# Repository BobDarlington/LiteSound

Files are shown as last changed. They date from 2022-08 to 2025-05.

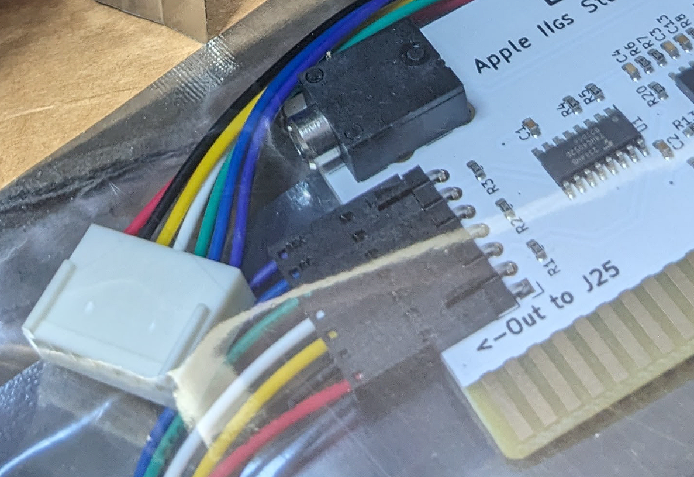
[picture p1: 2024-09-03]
cable-closeup.png

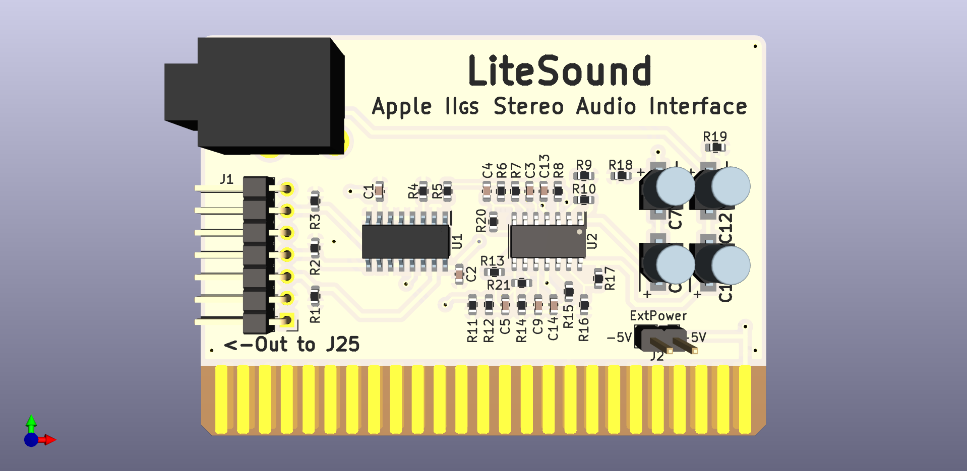
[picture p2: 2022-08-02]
IIGS-audio.png

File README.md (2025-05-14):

# LiteSound
This card provides stereo audio capability for the Apple IIGS computers.

This project was done in <b>KiCad 6.0.10</b> and may not work with older versions.

Installation and use manual is a Google Docs file and can be found at this URL:
https://tinyurl.com/39kpvvwv



The J25 header on the IIGS motherboard provides an analog audio signal, and address lines
to drive a demultiplexer which splits audio into Left & Right audio channels.

You can find partially made cables on eBay by searching for 7 pin 2510 or KF2510 cables, 30cm long.  
This length is "about right" and will reach all slots.  Pin 1 on the J25 goes to pin 7 on the LiteSound board.  
This is basically flipped or wired backwards.  Yeah, I should've caught this and may someday fix it.  
It's easy enough to just wire this way!   Included is a closeup photo of both ends of the cable, one end
attached to the PCB, and the other with the alignment tabs for the J25 end clearly visible.

The pins I use are [Molex 16-02-0103](https://www.mouser.com/ProductDetail/538-16-02-0103) on the LightSound end,
and the housings are [Molex 50-57-9207](https://www.mouser.com/ProductDetail/538-50-57-9207).

I'm using a [74HC4052D](https://www.digikey.com/en/products/detail/toshiba-semiconductor-and-storage/74HC4052D/6109174) demultiplexer
and a [TL074CDR](https://www.digikey.com/en/products/detail/texas-instruments/TL074CDR/276926) quad audio op-amp.  There are other pin-compatible
chips that can be substituted.

The headphone jack I use is a [CUI Devices SJ1-3515N](https://www.mouser.com/ProductDetail/490-SJ1-3515N) and the
7 pin header is an [Amphenol 77315-124-07LF](https://www.mouser.com/ProductDetail/649-77315-124-07LF).

Current(ish) board rendering:
[PCB rendering](IIGS-audio.png)

This rendering shows a 2 pin header that was added at the request of about two people who wanted the ability to power this board externally.   
This is not the norm, but you <B>can</b> do it if you really want to.  It's your GS, you do with it as you please!  This doesn't mean external to
the case, just external to the slot (with +/-5v wires run to the pcb) so you don't have to tie up a slot.   This is on you to figure out
how to do.  The only ground on this board is the analog ground on the J25 header on the motherboard.  Don't tie analog ground to digital ground 
(it says so right on the GS schematic).   This will introduce noise, as will decoupling capacitors between +/-5v and digital ground.  That's
why they're not on the board.

This is technically the 4th revision of the PCB.   1st rev worked fine, but was too short for PCBWay to be able to bevel the card edge.   2nd rev was bigger with some
parts moved around where it would be natural to accidentally pull the audio coupling capacitors off the board.  Initially I was using low profile SMT tantalum capacitors for this.
People had a real problem with the idea of using tants so I switched to the SMT electrolytic caps.  3rd rev moved those caps to where they are now,
but also included coupling caps for the power supplies to DC ground.  I learned the hard way not to do this.  Don't do it.   Noise will be introduced.
4th rev removed those two capacitors and added the two pin header.

<b>Known issue:</b> This stereo sound card makes a chirp / squawk sound when the IIGS is switched off if a Reactive Mircro power supply is installed.   This does not happen
if your system uses an original power supply and does not impact performance in any way.  It may do the same with other aftermarket power supplies. YMMV.

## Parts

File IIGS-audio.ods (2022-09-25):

Item | Qty | Reference(s) |  | Value | LibPart | Footprint | Datasheet | Arrow Part Number | Arrow Price/Stock | Description | Height | Manufacturer_Name | Manufacturer_Part_Number | Mouser Part Number | Mouser Price/Stock
1 | 4 | C1, C2, C13, C14 | https://www.digikey.com/en/products/detail/samsung-electro-mechanics/CL10B104KB8NNWC/3887593 | 0.1uF | Device:C | Capacitor_SMD:C_0603_1608Metric | ~
2 | 4 | C3, C4, C5, C9 | https://www.digikey.com/en/products/detail/samsung-electro-mechanics/CL10B152KB8WPNC/5961150 | 1.5nF | Device:C_Small | Capacitor_SMD:C_0603_1608Metric | ~
3 | 4 | C6, C7, C11, C12 |  | 10uF | SamacSys_Parts:VZT100M1HTR-0406 | CAPAE430X610N | https://www.mouser.co.uk/datasheet/2/231/156315576075-1624351.pdf |  |  | Aluminum Electrolytic Capacitors - SMD 10uF 20% 50V Ultra Low ESR | 6.1 | Lelon | VZT100M1HTR-0406 | 140-VZT100M1HTR-0406 | https://www.mouser.co.uk/ProductDetail/Lelon/VZT100M1HTR-0406/?qs=mQP6vorrPAcP1%252BjIAgEecA%3D%3D
4 | 1 | J1 |  | Conn_01x07 | Connector_Generic:Conn_01x07 | Connector_PinHeader_2.54mm:PinHeader_1x07_P2.54mm_Horizontal | ~
5 | 1 | J2 |  | Conn_01x02_Male | Connector:Conn_01x02_Male | Connector_PinHeader_2.54mm:PinHeader_1x02_P2.54mm_Vertical | ~
6 | 1 | J3 | https://www.digikey.com/en/products/detail/cui-devices/SJ1-3515N/738684 | SJ1-3515N | SamacSys_Parts:SJ1-3515N | SJ13515N | https://componentsearchengine.com/Datasheets/1/SJ1-3515N.pdf |  |  | AUDIOJACK, 3.5MM, RT, STEREO, | 6 | CUI Inc. | SJ1-3515N | 490-SJ1-3515N | https://www.mouser.co.uk/ProductDetail/CUI-Devices/SJ1-3515N?qs=WyjlAZoYn51jeVVXLxifpg%3D%3D
7 | 1 | J4 | This is the card edge connector itself on the PCB | AppleII_slot | appleii_slot:AppleII_slot | Apple2:Apple2_card_slot
8 | 17 | R1, R2, R3, R4, R5, R6, R7, R8, R9, R11, R12, R13, R14, R15, R16, R20, R21 | https://www.digikey.com/en/products/detail/bourns-inc/CR0603-FX-1002ELF/3593188 | 10K | Device:R_US | Resistor_SMD:R_0603_1608Metric | ~
9 | 2 | R10, R17 | https://www.digikey.com/en/products/detail/bourns-inc/CR0603-FX-1502ELF/3740908 | 15K | Device:R_US | Resistor_SMD:R_0603_1608Metric | ~
10 | 2 | R18, R19 | https://www.digikey.com/en/products/detail/bourns-inc/CR0603-FX-5602ELF/3784093 | 56k | Device:R_US | Resistor_SMD:R_0603_1608Metric | ~
11 | 1 | U1 | https://www.digikey.com/en/products/detail/toshiba-semiconductor-and-storage/74HC4052D/6109174 | 74HC4052D | SamacSys_Parts:MC14052BDR2G | SOIC127P600X175-16N | http://www.onsemi.com/pub/Collateral/MC14051B-D.PDF | MC14052BDR2G | https://www.arrow.com/en/products/mc14052bdr2g/on-semiconductor?region=nac |  | 1.75 | ON Semiconductor | MC14052BDR2G | 863-MC14052BDR2G | https://www.mouser.co.uk/ProductDetail/onsemi/MC14052BDR2G?qs=OSf9jACorvZ82JRMsgs01Q%3D%3D
12 | 1 | U2 | https://www.digikey.com/en/products/detail/texas-instruments/TL074CDR/276926 | TL074 | Amplifier_Operational:TL084 | Package_SO:SOIC-14_3.9x8.7mm_P1.27mm | http://www.ti.com/lit/ds/symlink/tl081.pdf

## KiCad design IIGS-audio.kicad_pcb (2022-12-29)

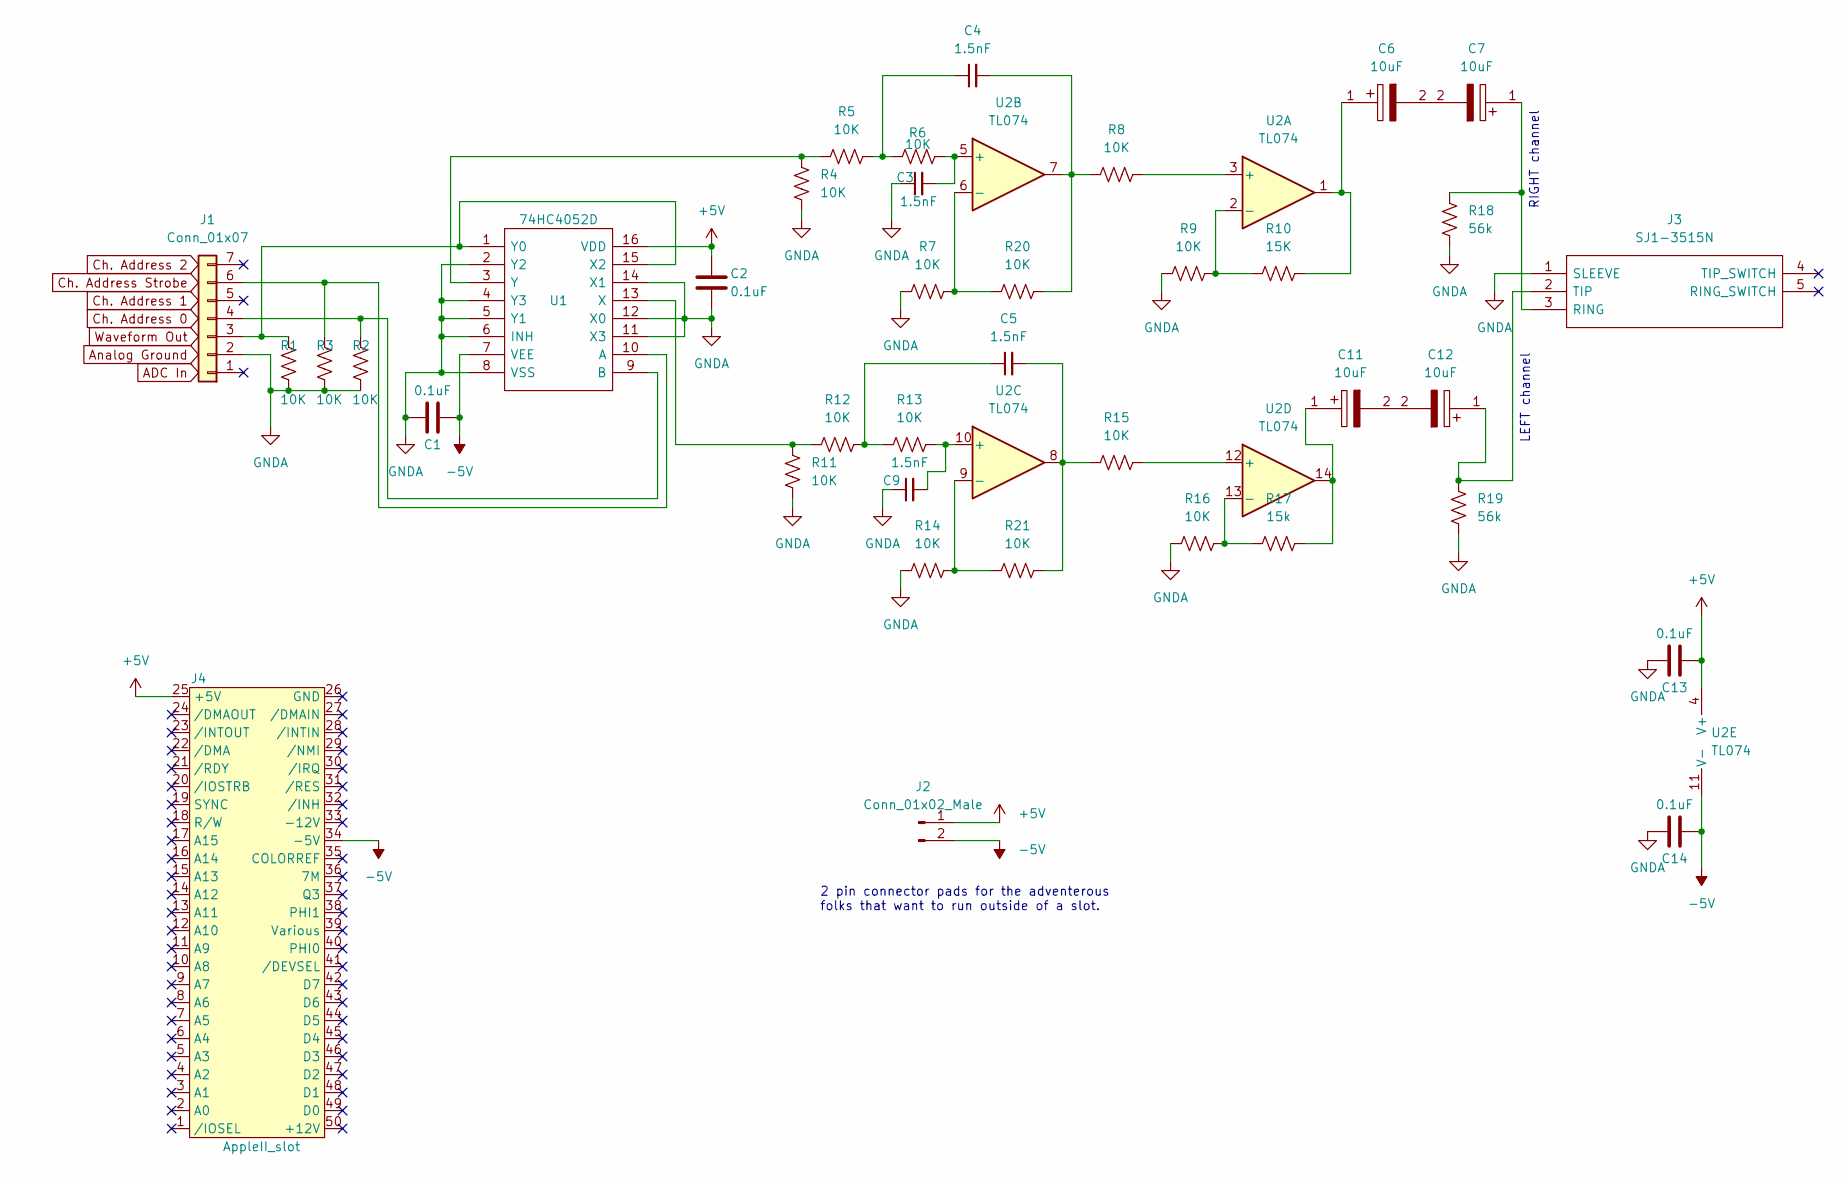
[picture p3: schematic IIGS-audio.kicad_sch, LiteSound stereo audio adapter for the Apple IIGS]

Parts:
C1, C2, C13, C14: 0.1uF; C_0603_1608Metric
C3, C4, C5, C9: 1.5nF; C_0603_1608Metric
C6, C7, C11, C12: 10uF; CAPAE430X610N; Mouser Part Number 140-VZT100M1HTR-0406
J1: Conn_01x07; PinHeader_1x07_P2.54mm_Horizontal
J2: Conn_01x02_Male; PinHeader_1x02_P2.54mm_Vertical
J3: SJ1-3515N; SJ13515N; Mouser Part Number 490-SJ1-3515N
J4: AppleII_slot; Apple2_card_slot
R1, R2, R3, R4, R5, R6, R7, R8, R9, R11, R12, R13, R14, R15, R16, R20, R21: 10K; R_0603_1608Metric
R10: 15K; R_0603_1608Metric
R17: 15k; R_0603_1608Metric
R18, R19: 56k; R_0603_1608Metric
U1: 74HC4052D; SOIC127P600X175-16N; Manufacturer_Part_Number MC14052BDR2G; Mouser Part Number 863-MC14052BDR2G
U2: TL074; SOIC-14_3.9x8.7mm_P1.27mm

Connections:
+5V: C2.1, C13.2, J2.1, J4.25 (+5V), U1.16 (VDD), U2.4 (V+)
-5V: C1.2, C14.2, J2.2, J4.34 (-5V), U1.7 (VEE), U2.11 (V-)
GNDA: C1.1, C2.2, C3.1, C9.1, C13.1, C14.1, J1.2, J3.1 (SLEEVE), R1.1, R2.1, R3.1, R4.1, R7.2, R9.2, R11.1, R14.2, R16.2, R18.1, R19.1, U1.2 (Y2), U1.4 (Y3), U1.5 (Y1), U1.6 (INH), U1.8 (VSS), U1.11 (X3), U1.12 (X0), U1.14 (X1)
unnamed: C3.2, R6.2, U2.5 (+)
unnamed: C4.1, R5.2, R6.1
unnamed: C4.2, R8.1, R20.1, U2.7
unnamed: C5.1, R12.2, R13.1
unnamed: C5.2, R15.1, R21.1, U2.8
unnamed: C6.1, R10.2, U2.1
unnamed: C6.2, C7.2
unnamed: C7.1, J3.3 (RING), R18.2
unnamed: C9.2, R13.2, U2.10 (+)
unnamed: C11.1, R17.2, U2.14
unnamed: C11.2, C12.2
unnamed: C12.1, J3.2 (TIP), R19.2
unnamed: J1.3, R1.2, U1.1 (Y0), U1.15 (X2)
unnamed: J1.4, R2.2, U1.9 (B)
unnamed: J1.6, R3.2, U1.10 (A)
unnamed: R4.2, R5.1, U1.3 (Y)
unnamed: R8.2, U2.3 (+)
unnamed: R9.1, R10.1, U2.2 (-)
unnamed: R11.2, R12.1, U1.13 (X)
unnamed: R14.1, R21.2, U2.9 (-)
unnamed: R15.2, U2.12 (+)
unnamed: R16.1, R17.1, U2.13 (-)
unnamed: R7.1, R20.2, U2.6 (-)

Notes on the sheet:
2 pin connector pads for the adventerous folks that want to run outside of a slot.
LEFT channel
RIGHT channel

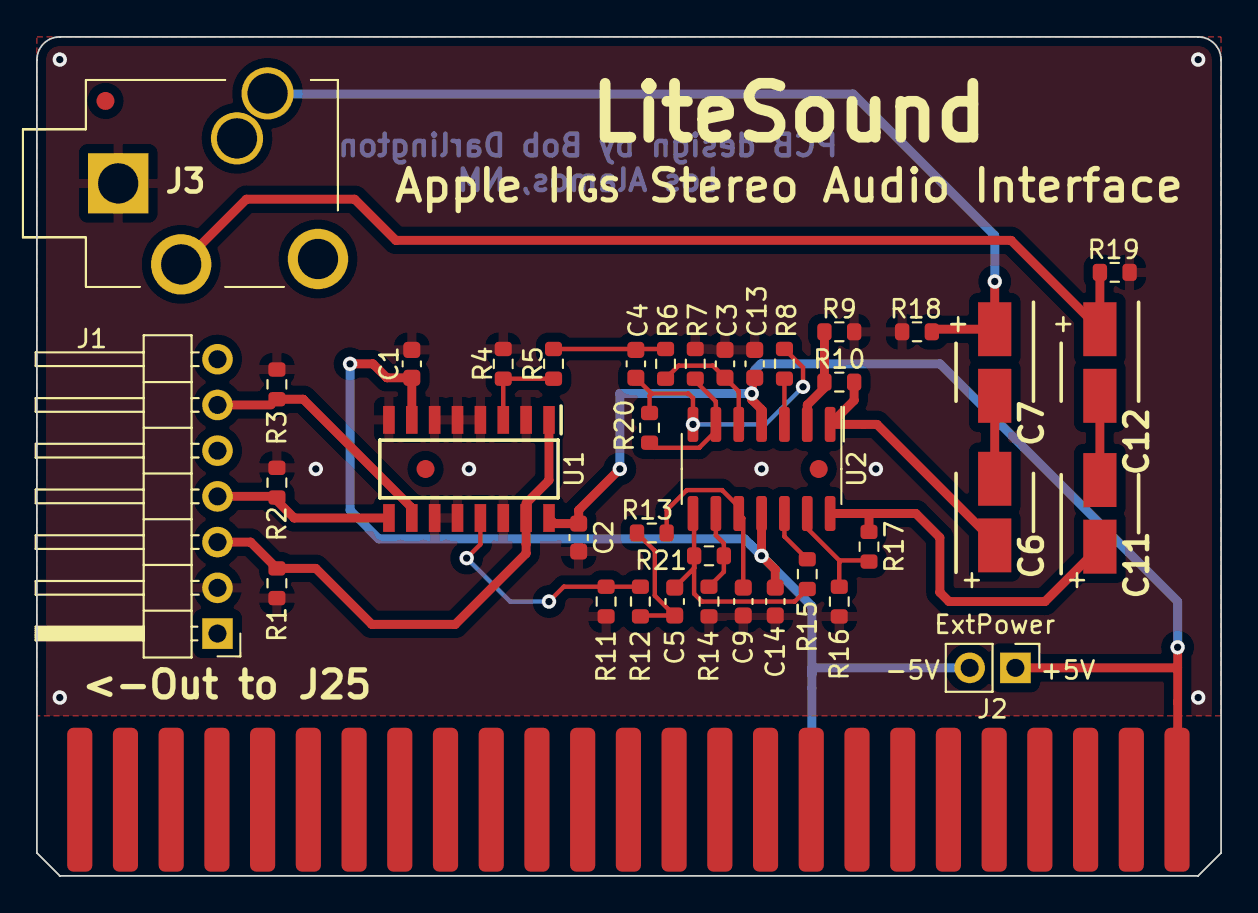
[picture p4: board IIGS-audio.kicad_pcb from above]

Board: 2 copper layers, 65.8 x 46.6 mm, 42 parts (0 on the bottom side), 26 nets.

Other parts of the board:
REF01, REF02, REF03: Fiducial_1mm_Mask2mm

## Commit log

2022-07-12 Initial upload of files
    [IIGS-audio.csv, IIGS-audio.kicad_pcb, IIGS-audio.kicad_sch]
2022-07-12 Added specific parts used on the PCB
2022-07-15 minor tweaks, got rid of PSU rail caps because they contributed to noise
    [IIGS-audio.kicad_pcb, IIGS-audio.kicad_sch]
2022-07-15 Current layout rendering
2022-07-15 Added PCB rendering and updated README.md
2022-07-15 Updated the PCB image
2022-07-16 Updated to reflect current layout.
2022-07-26 Added a blurb about aftermarket power supplies
2022-07-26 Updated readme to include information about aftermarket power supplies
2022-07-26 Upgraded KiCad
    [IIGS-audio.kicad_sch]
2022-07-26 Update README.md
    Rev'd the KiCad version number
2022-07-26 Changed silkscreen label from J-25 to J25 to match the IIGS motherboard
    [IIGS-audio.kicad_pcb]
2022-07-26 Changed silkscreen label from J-25 to J25 to match IIGS motherboard
    [IIGS-audio.kicad_pcb]
2022-07-26 Updated rendering to match current PCB rev.
2022-08-02 Minor layout tweaks.
    [IIGS-audio.kicad_pcb]
2022-08-02 Minor tweaks to layout
    [IIGS-audio.kicad_pcb]
2022-08-03 Exploring fiducial markers
    [IIGS-audio.kicad_pcb]
2022-08-03 Added fiducial markers for pick and place machines.
    [IIGS-audio.kicad_pcb]
2022-08-03 Adjusted fiducials for PnP machines. Hid them under components.
    [IIGS-audio.kicad_pcb]
2022-08-04 Excluded the gerber ouput directory
2022-09-25 Changed the output directory name for gerber files.
    [IIGS-audio.kicad_pcb]
2022-09-25 Added a URL to the user manual
    [IIGS-audio.ods]
2022-12-29 Updated fiducial markers
    [IIGS-audio.kicad_pcb]
2022-12-29 Set origin and upgraded to KiCAD 6.0.10
    [IIGS-audio.kicad_pcb]
2022-12-29 Reved the KiCAD version number
2024-09-03 Added a photo of the cable so folks can wire it correctly to the J25 connector on the mobo.
2024-09-03 Added part numbers and info about the cable and corrected spelling.
